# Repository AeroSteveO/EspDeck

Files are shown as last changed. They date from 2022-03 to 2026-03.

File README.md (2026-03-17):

# EspDeck

This is a StreamDeck inspired macro pad powered by EspHome for use with Home Assistant. Each key has 3 different actions it can perform, single click, double click, and click + hold. These can all be tied to different automations in Home Assistant. This project is made for ESPHome (hardware + ESPHome Configuration).

Made for ESPHome (https://esphome.io/guides/made_for_esphome.html)

# Functionality
ESPDeck provides a macropad type input set to Home Assistant based on ESPHome. This includes 3 modes of input for each keyswitch. 

  * Single Click
  * Double Click
  * Click and Hold

# Variants
There are a number of variants of the device in this repository. The standard EspDeck is a 9 key pad. There is also the novelkey macropad, which has two BIG switches, and an upcoming design to add NFC functionality to the EspDeck macropad (NfcDeck). All of these use the same basic features in ESPHome and previous iterations of the designs are maintained for legacy support. Do look at the variant specific README files for the hardware needed, 3d print files, and yaml configurations.

## EspDeck
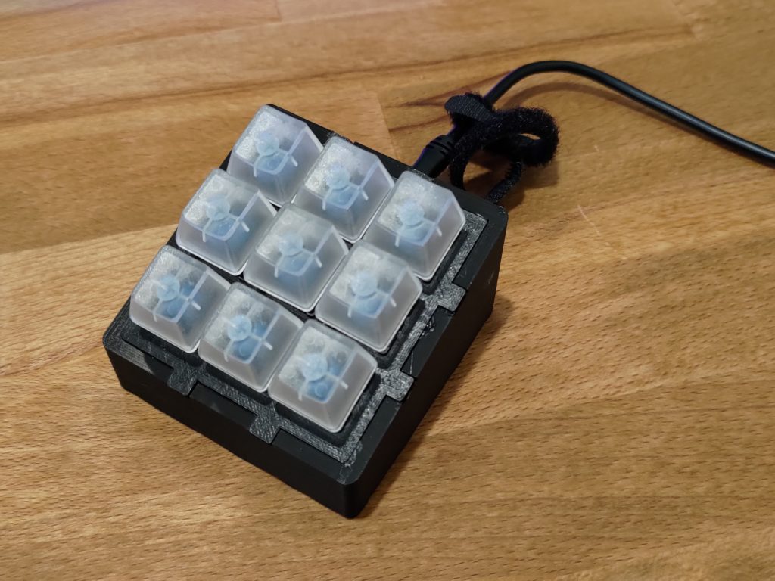
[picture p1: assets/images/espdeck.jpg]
EspDeck


There are also previous generation EspDecks ([Gen 1](/espdeck/GEN1_README.md), [Gen 2](/espdeck/GEN2_README.md)) in this repository.

## NfcDeck
NfcDeck

### Additional Functionality

  * NFC Card Reader
  * Rotary Encoder
  * Per Key Addressable Backlighting

## Novelkey Novelty macropad
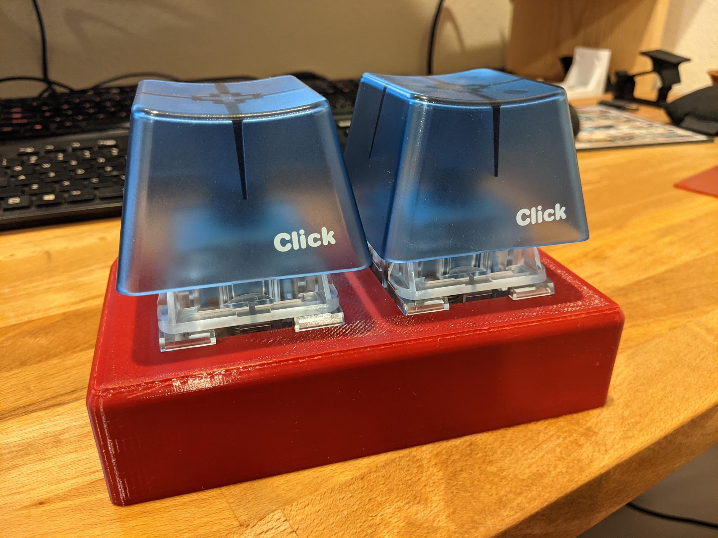
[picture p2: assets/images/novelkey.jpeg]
Novelkey Novelty Big Switch Macropad


### Additional Functionality

  * Per Key LED Backlighting
  * BIG switches

# Hardware Used
  * 1 x ESP8266 / NodeMCU
  * 9 x Relegendable KeyCaps (waterslide decal paper can also be used with existing keycaps, especially blank ones)
  * 9 x Mechanical key switches
  * Hot Glue
  * 3d printer material
  * various wire

# STL Files for 3D Printing
All the case designs can be found on Github, [Printables](https://www.printables.com/@AeroSteveO/collections/1135401), and [Thingiverse](https://www.thingiverse.com/aerosteveo/collections/40893020/things)

# Configuration
EspHome YAML files are included with each project and are versioned to allow for legacy device support.

# Printing Instructions
These can be printed with low infill for speed and with a medium to thick layer height, they don't need a fine layer height to print well. All the designs are intended to be printed without supports (except the main enclosure for the novelkey novelty macropad). 

# Contributing
Contributions are welcome to the project

# Change Log

  * With generation 2, we simplified the design, reducing the number of resistors needed in the wiring.
  * With generation 3, we begin to use the Matrix Keypad feature of EspHome, simplifying the wiring.

# To Do:
  * Update the case designs to use heat set inserts to make them more maintainable rather than hot gluing the top down, also more professional
  * Add WS2812 LEDs to backlight the key switches, providing an aveneue for notifying of a status from home assistant on the OG ESP Deck Designs
  * Create a 3 key NFC deck variant with 2 key switches and a rotary (or keyswitch for the third)

# Star History
(you guys rock)
Star History Chart (https://www.star-history.com/#AeroSteveO/EspDeck&type=date&legend=top-left)

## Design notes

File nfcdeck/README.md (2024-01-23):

# NFC Deck
This is a complex iteration of the EspDeck in order to allow control of multi room audio systems (or anything else you want to use it for). There are two top panel iterations, one for 9 mechanical key switches, and one for 8 key switches and one rotary encoder.

# Variants:
  * 8 Keys, 1 Rotary Knob
  * 9 Keys
  * 2 Keys, 1 Rotary Knob
  * 3 Keys

# Components:
Since this has a few different variants you can build. We split the parts list up into the common parts for all models, and then the parts specific to each model. This are mostly different based on the counts for different parts.

## Common to All
  * ESP32 DevKitv1
  * 1 x NFC Card Reader
  * 1 x Piezo Buzzer
  * 4 x [Rubber Feet](https://www.amazon.com/dp/B06XPCLN23)
  * 4 x M2 heat set inserts
  * 4 x M2 screws

## 9 Key + Rotary
  * 8  x Mechanical Key Switches
  * 8  x Relegendable Key Caps
  * 1  x Rotary Encoder
  * 1  x Knob
  * 8  x WS2812 LEDs (60 LED per M, or 16.5mm interval)
  * 2  x 100 ohm resistors
  * 2  x 1 uf capcitors

## 9 Key
  * 9  x Mechanical Key Switches
  * 9  x Relegendable Key Caps
  * 9  x WS2812 LEDs (60 LED per M, or 16.5mm interval)

## 3 Key + Rotary
  * 2  x Mechanical Key Switches
  * 2  x Relegendable Key Caps
  * 1  x Rotary Encoder
  * 1  x Knob
  * 2  x WS2812 LEDs (60 LED per M, or 16.5mm interval)
  * 2  x 100 ohm resistors
  * 2  x 1 uf capcitors

## 3 Key
  * 3  x Mechanical Key Switches
  * 3  x Relegendable Key Caps
  * 3  x WS2812 LEDs (60 LED per M, or 16.5mm interval)

# Circuit Diagram
NFC Deck Circuit Diagram

## Breaking the circuits down into individual components
9 Key Circuit Diagram
Buzzer Circuit Diagram
LED Strip Circuit Diagram
NFC Circuit Diagram

Rotary Encoder Circuit Diagram

# Wiring
- Assemble a small circuit board with the rotary encoder 

# Assembly

- Print out the top plate, and mount all of your key switches to it and the rotary encoder.
- Solder all the key switches and rotary up to the D1 Mini

Also, make sure that you have set the switches on the PN532 to the following:
- Switch 1: On (up)
- Switch 2: Off (down)

This enables the PN532 module to communicate with the D1 over I2C, and is required for the modules to work together!

- Optionally electrical tape over the NFC module power LED

Mount the NFC module to the top plate

# Printing Instructions
Print one each of:

 *  nfcdeck_base.stl
 *  NfcDeck Top Piece (one of either option)
	*  nfcdeck_top_rotary.stl (with a space for a rotary encoder)
	*  nfcdeck_top_9key.stl   (with 9 key switches and no rotary encoder)

These can be low infill as they don't require much structural stability
Do use a slightly larger layer thickness for the top piece, 0.15mm is good, or more. The details come out a bit better in the home assistant logo using that higher layer thickness.

Work is still continuing on the 3 key designs, so they aren't yet available.

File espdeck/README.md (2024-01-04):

# EspDeck

This is a StreamDeck inspired macro pad powered by EspHome for use with Home Assistant. Each key has 3 different actions it can perform, single click, double click, and click + hold. These can all be tied to different automations in Home Assistant. This project is made for ESPHome (hardware + ESPHome Configuration).

Made for ESPHome (https://esphome.io/guides/made_for_esphome.html)

# Functionality
ESPDeck provides a macropad type input set to Home Assistant based on ESPHome. This includes 3 modes of input for each keyswitch. 

  * Single Click
  * Double Click
  * Click and Hold

See also the previous generation EspDecks ([Gen 1](GEN1_README.md), [Gen 2](GEN2_README.md)) in this repository.

# Hardware Used
  * 1 x ESP8266 / NodeMCU
  * 9 x Relegendable KeyCaps (waterslide decal paper can also be used with existing keycaps, especially blank ones)
  * 9 x Mechanical key switches
  * Hot Glue
  * 3d printer material
  * various wire

# Case

Case design based off of: https://www.thingiverse.com/thing:5204033. I extended the height of the case for my inefficient use of space inside of it, I also made some modifications to better hold the Esp8266. The top of the case is currently press fit or hot glued on, though I'll be working on making it a screw in place top in the future.

Case design can also be found here: https://www.thingiverse.com/thing:5223223

# Wiring
The wiring is simple enough, we make use of the matrix keypad feature and wire the columns and rows to inputs on the ESP. We avoid GPIO15 as it doesn't have an internal pullup as well, simplifying our wiring.

Third Generation Circuit Diagram

# Configuration

keypad3.yaml

# Printing Instructions
Print one each of:
  * MacroPadBottomExtended.stl
  * MacroPadTop.stl

These can be printed with low infill for speed.

# Contributing
Contributions are welcome to the project

# Change Log

  * With generation 3, we begin to use the Matrix Keypad feature of EspHome, simplifying the wiring.
  * With generation 4, we'll be adding WS2812 LEDs to backlight the key switches, providing an aveneue for notifying of a status from home assistant

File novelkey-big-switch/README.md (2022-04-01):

# Novelkey "The Big Switch" ESP Home MacroPad
This is a simple 2 switch ESP Home based macropad for use with home assistant. I built these for nightstand switches for the lights and overhead fan in the room (or as an excuse to play with the novelkeys big switches). They have RGB backlighting to provide feedback of what functionality is on what key (or whatever else you want to use the lighting for).

# Components:
  * ESP8266 / NodeMCU
  * 2 x [NovelKey "The Big Switch" mechanical keyboard switches](https://novelkeys.com/products/the-big-switch-series)
  * 2 x [Common Cathode RGB LEDs](https://www.amazon.com/dp/B0749MD16P)
  * 2 x [300 ohm resistors](https://www.amazon.com/dp/B07HDH7QK5)
  * 3 x [pairs of 3-pin JST plugs](https://www.amazon.com/gp/product/B071H5XCN5) (I got them originally for WLED strips)
  * 4 x [Rubber Feet](https://www.amazon.com/dp/B06XPCLN23)

# Circuit Diagram
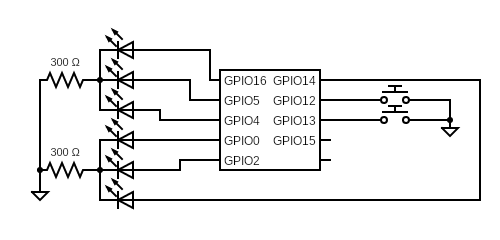
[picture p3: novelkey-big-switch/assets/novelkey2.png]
First Generation Circuit Diagram


# Printing Instructions
Print one each of:

 *  big_base.stl
 *  big_bottom.stl
 *  big_cover.stl

These can be low infill as they don't require much structural stability

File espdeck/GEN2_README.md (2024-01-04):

# EspDeck

This is a StreamDeck inspired macro pad powered by EspHome for use with Home Assistant. Each key has 3 different actions it can perform, single click, double click, and click + hold. These can all be tied to different automations in Home Assistant. This project is made for ESPHome (hardware + ESPHome Configuration).

Made for ESPHome (https://esphome.io/guides/made_for_esphome.html)

# Functionality
ESPDeck provides a macropad type input set to Home Assistant based on ESPHome. This includes 3 modes of input for each keyswitch. 

  * Single Click
  * Double Click
  * Click and Hold

See also the Novelkey Novelty Big Switch Macropad and the [Gen 1 EspDeck](GEN1_README.md) is also documented.

# Hardware Used
  * 1 x ESP8266 / NodeMCU
  * 9 x Relegendable KeyCaps (waterslide decal paper can also be used with existing keycaps, especially blank ones)
  * 9 x Mechanical key switches
  * 1 x 10k Resistor
  * Hot Glue
  * 3d printer material
  * various wire

# Case

Case design based off of: https://www.thingiverse.com/thing:5204033. I extended the height of the case for my inefficient use of space inside of it, I also made some modifications to better hold the Esp8266. The top of the case is currently press fit or hot glued on, though I'll be working on making it a screw in place top in the future.

Case design can also be found here: https://www.thingiverse.com/thing:5223223

# Wiring
The wiring is simple enough, one end of the switch going to the digitial IO pin, and the other end to ground, and set up ESPHome to have the internal pullup enabled on the ESP8266 device. Two of the GPIOs on the device cannot be done this way, GPIO16 needs an external pullup resistor, and GPIO15 needs to be inverted (internal pulldown, external pullup).

Second Generation Circuit Diagram

Second Generation Circuit Diagram Simplified

# Configuration

keypad2.yaml

# Printing Instructions
Print one each of:
  * MacroPadBottomExtended.stl
  * MacroPadTop.stl

These can be printed with low infill for speed.

# Contributing
Contributions are welcome to the project

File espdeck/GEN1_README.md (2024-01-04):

# Functionality
ESPDeck provides a macropad type input set to Home Assistant based on ESPHome. This includes 3 modes of input for each keyswitch. 

  * Single Click
  * Double Click
  * Click and Hold

# Hardware Used
  * 1 x ESP8266 / NodeMCU
  * 9 xRelegendable KeyCaps (waterslide decal paper can also be used with existing keycaps, especially blank ones)
  * 9 x Mechanical key switches
  * Hot Glue
  * 3d printer material
  * 9 x 10k Ohm Resistors

# Wiring
## Gen1 Design
3.3V to the switches

10k to ground for each Digitial IO Pin, as well as a line to the switch

First Generation Circuit Diagram

# Configuration
keypad.yaml

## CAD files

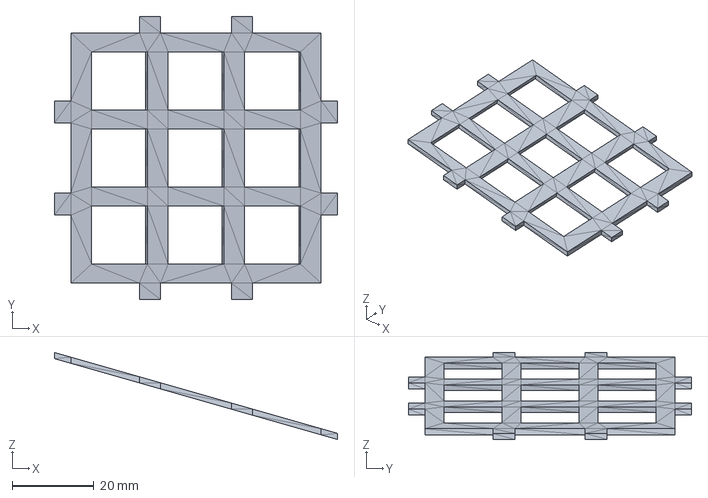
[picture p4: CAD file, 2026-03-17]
espdeck/MacroPadTop.stp
69.4 x 69.4 x 21.3 mm

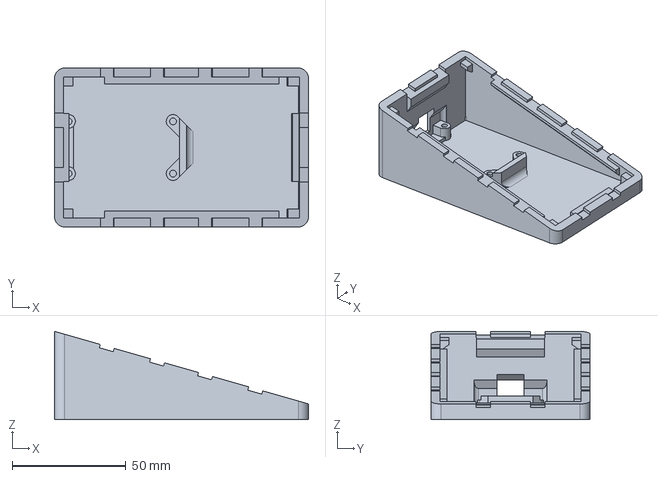
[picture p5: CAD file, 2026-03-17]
nfcdeck/case_models/nfcdeck_base.stp
111.8 x 70.0 x 38.9 mm

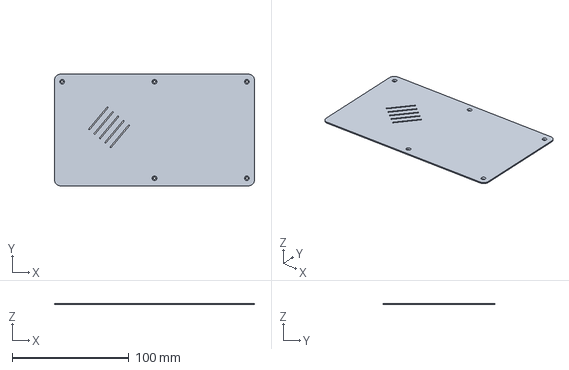
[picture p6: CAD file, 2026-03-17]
novelkey-big-switch/big_bottom.stp
171.6 x 95.8 x 1.00 mm

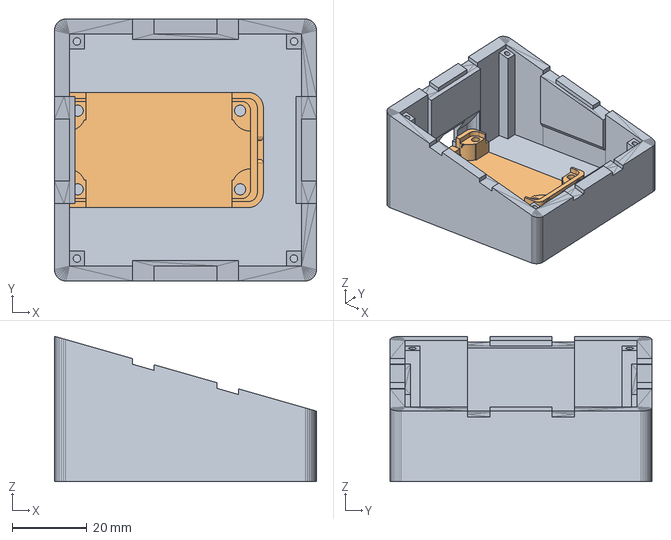
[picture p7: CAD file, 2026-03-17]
espdeck/MacroPadBotom.stp
70.0 x 70.0 x 38.8 mm

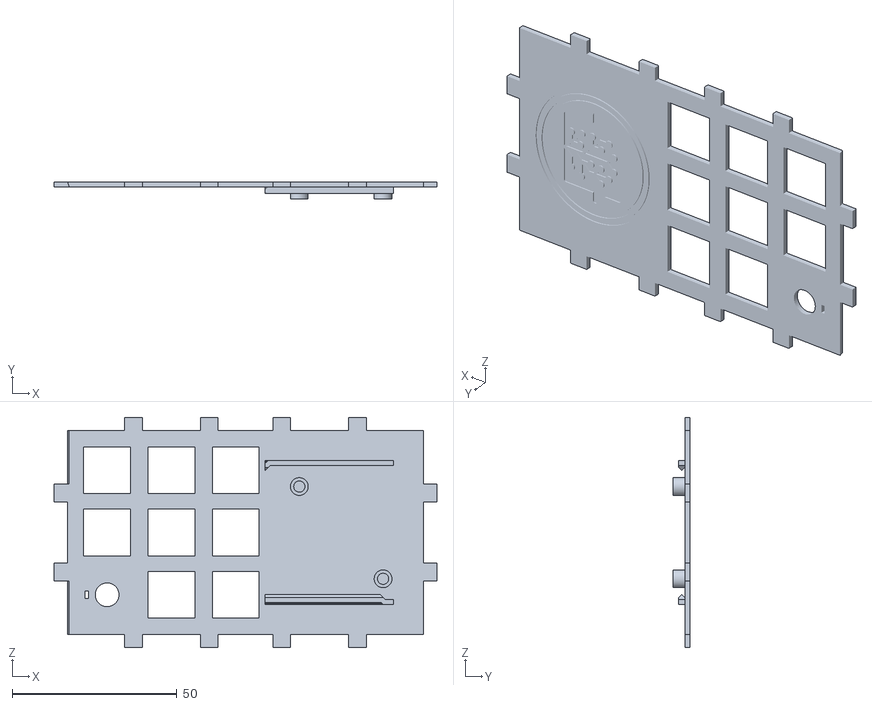
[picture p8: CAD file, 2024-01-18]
nfcdeck/case_models/nfcdeck_top_rotary.stl
116.2 x 5.10 x 69.9

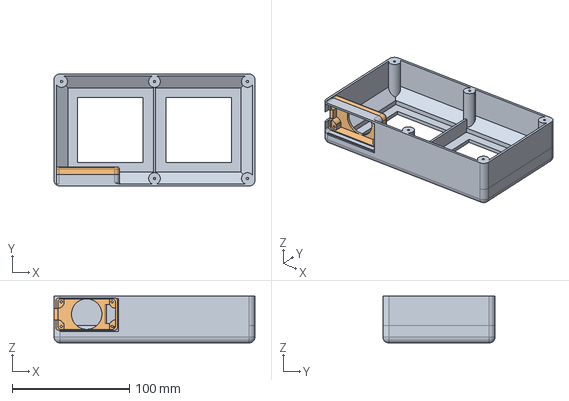
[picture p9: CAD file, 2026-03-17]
novelkey-big-switch/big_base.stp
171.6 x 95.8 x 40.0 mm

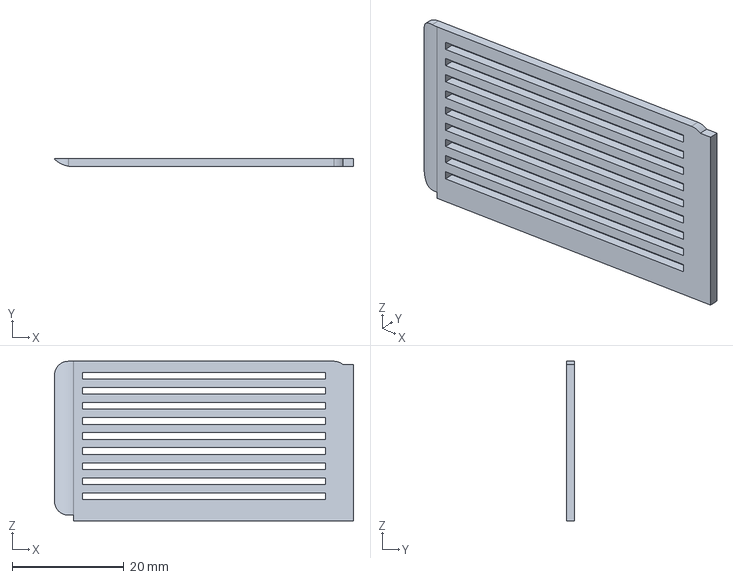
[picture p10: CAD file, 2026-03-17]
novelkey-big-switch/big_cover.stp
53.6 x 1.50 x 28.6 mm

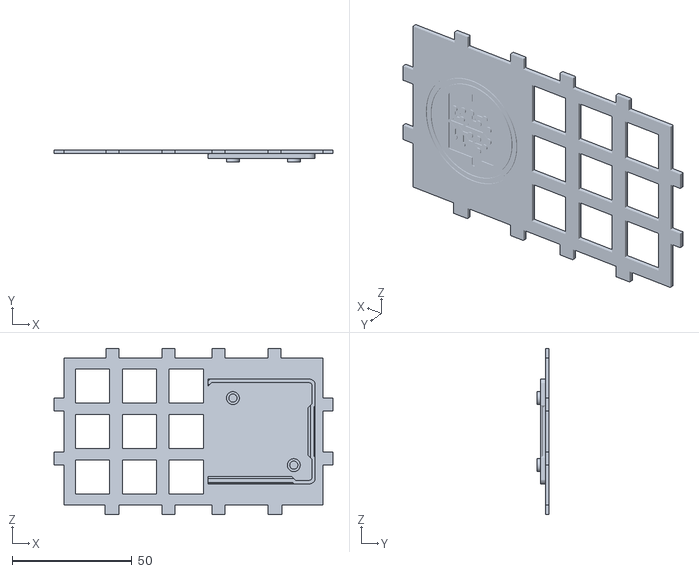
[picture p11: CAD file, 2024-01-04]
nfcdeck/case_models/nfcdeck_top.stl
116.5 x 5.10 x 69.4

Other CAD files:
espdeck/MacroPadBottomExtended.stl
nfcdeck/case_models/nfcdeck_top_9key.stl
espdeck/MacroPadTop.stl
nfcdeck/case_models/nfcdeck_base.stl
novelkey-big-switch/big_base.stl
novelkey-big-switch/big_bottom.stl
novelkey-big-switch/big_cover.stl

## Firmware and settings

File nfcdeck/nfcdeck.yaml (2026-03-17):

esphome:
  name: esphome-web-asdf
  friendly_name: NfcDeck
  project:
    name: aerosteveo.nfc_deck
    version: "1.0"
  # If buzzer is enabled, notify on api connection success
  on_boot:
    priority: -10
    then:
    - lambda: !lambda |-
            id(key_1_click_state).publish_state(false);
            id(key_2_click_state).publish_state(false);
            id(key_3_click_state).publish_state(false);
            id(key_4_click_state).publish_state(false);
            id(key_5_click_state).publish_state(false);
            id(key_6_click_state).publish_state(false);
            id(key_7_click_state).publish_state(false);
            id(key_8_click_state).publish_state(false);
            id(key_9_click_state).publish_state(false);
            id(key_1_held_state).publish_state(false);
            id(key_2_held_state).publish_state(false);
            id(key_3_held_state).publish_state(false);
            id(key_4_held_state).publish_state(false);
            id(key_5_held_state).publish_state(false);
            id(key_6_held_state).publish_state(false);
            id(key_7_held_state).publish_state(false);
            id(key_8_held_state).publish_state(false);
            id(key_9_held_state).publish_state(false);
            id(key_1_double_click_state).publish_state(false);
            id(key_2_double_click_state).publish_state(false);
            id(key_3_double_click_state).publish_state(false);
            id(key_4_double_click_state).publish_state(false);
            id(key_5_double_click_state).publish_state(false);
            id(key_6_double_click_state).publish_state(false);
            id(key_7_double_click_state).publish_state(false);
            id(key_8_double_click_state).publish_state(false);
            id(key_9_double_click_state).publish_state(false);
    - wait_until:
        api.connected:
    - logger.log: API is connected!
    - rtttl.play: "success:d=24,o=5,b=100:c,g,b"
    - light.turn_on:
        id: activity_led
        brightness: 100%
        red: 0%
        green: 0%
        blue: 100%
        flash_length: 500ms
    - switch.turn_on: buzzer_enabled
    - switch.turn_on: led_enabled

substitutions:
  name: esphome-web-asdf
  friendly_name: NfcDeck
  nine_key_pin_1: "13"
  nine_key_pin_2: "12"
  nine_key_pin_3: "14"
  nine_key_pin_4: "27"
  nine_key_pin_5: "26"
  nine_key_pin_6: "25"
  i2c_sda_pin: "23"
  i2c_scl_pin: "22"
  buzzer_output_pin: "1"
  rotary_pin_a: "3"
  rotary_pin_b: "21"
  neopixelbus_pin: "19"

esp32:
  board: esp32dev
  framework:
    type: esp-idf

# This should point to the public location of this yaml file.
dashboard_import:
  package_import_url: github://AeroSteveO/EspDeck/nfcdeck/nfcdeck.yaml

# Enable logging
logger:

# Enable Home Assistant API
api:
  encryption:
    key: "asdfasdfasdfasdfasdfasdf"
  services:
  - service: rfidreader_tag_ok
    then:
    - rtttl.play: "beep:d=16,o=5,b=100:b"
  - service: rfidreader_tag_ko
    then:
    - rtttl.play: "beep:d=8,o=5,b=100:b"

  - service: play_rtttl
    variables:
      song_str: string
    then:
    - rtttl.play: !lambda 'return song_str;'

  - service: write_tag_id
    variables:
      tag_id: string
    then:
    - light.turn_on:
        id: activity_led
        brightness: 100%
        red: 100%
        green: 0%
        blue: 0%    
    - lambda: |-
        auto message = new nfc::NdefMessage();
        std::string uri = "https://www.home-assistant.io/tag/";
        uri += tag_id;
        message->add_uri_record(uri);
        id(pn532_board).write_mode(message);
    - rtttl.play: "write:d=24,o=5,b=100:b"
    - wait_until:
        not:
          pn532.is_writing:
    - light.turn_off:
        id: activity_led
    - rtttl.play: "write:d=24,o=5,b=100:b,b"

  - service: write_music_tag
    variables:
      music_url: string
      music_info: string
    then:
    - light.turn_on:
        id: activity_led
        brightness: 100%
        red: 100%
        green: 0%
        blue: 0%    
    - lambda: |-
        auto message = new nfc::NdefMessage();
        std::string uri = "";
        std::string text = "";
        uri += music_url;
        text += music_info;
        if ( music_url != "" ) {
          message->add_uri_record(uri);
        }
        if ( music_info != "" ) {
          message->add_text_record(text);
        }
        id(pn532_board).write_mode(message);
    - rtttl.play: "write:d=24,o=5,b=100:b"
    - wait_until:
        not:
          pn532.is_writing:
    - light.turn_off:
        id: activity_led
    - rtttl.play: "write:d=24,o=5,b=100:b,b"

ota:
  platform: esphome

wifi:
  ssid: !secret wifi_ssid
  password: !secret wifi_password

  # Enable fallback hotspot (captive portal) in case wifi connection fails
  ap:
    ssid: "Esphome-Web-asdf"
    password: "asdfasdfasdfasdfasdf"

captive_portal:
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

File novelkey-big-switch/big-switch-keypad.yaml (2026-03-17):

esphome:
  name: novelkey2
  project:
    name: "NovelKey.v1"
    version: "1.0.0"

esp8266:
  board: esp12e

# Enable logging
logger:

# Enable Home Assistant API
api:
  password: ""

ota:
  platform: esphome
  password: ""

dashboard_import:
  package_import_url: github://AeroSteveO/EspDeck/novelkey-big-switch/big-switch-keypad.yaml

wifi:
  ssid: !secret wifi_ssid
  password: !secret wifi_password

  # Enable fallback hotspot (captive portal) in case wifi connection fails
  ap:
    ssid: "Novelkey2 Fallback Hotspot"
    password: "bigLongUniqueString"

captive_portal:


switch:
  - platform: gpio
    pin: 16
    id: red
    name: "Novelkey 1 Red"
    restore_mode: RESTORE_DEFAULT_OFF
    interlock: [blue,green]
  - platform: gpio
    pin: 5
    id: green
    name: "Novelkey 1 Green"
    restore_mode: RESTORE_DEFAULT_OFF
    interlock: [blue,red]
  - platform: gpio
    pin: 4
    id: blue
    name: "Novelkey 1 Blue"
    restore_mode: RESTORE_DEFAULT_OFF
    interlock: [red,green]
  - platform: gpio
    pin: 0
    id: red2
    name: "Novelkey 2 Red"
    restore_mode: RESTORE_DEFAULT_OFF
    interlock: [blue2,green2]
  - platform: gpio
    pin: 2
    id: green2
    name: "Novelkey 2 Green"
    restore_mode: RESTORE_DEFAULT_OFF
    interlock: [blue2,red2]
  - platform: gpio
    pin: 14
    id: blue2
    name: "Novelkey 2 Blue"
    restore_mode: RESTORE_DEFAULT_OFF
    interlock: [red2,green2]
binary_sensor:
  - platform: gpio
    pin:
      number: 12
      mode:
        input: true
        pullup: true
      inverted: true
    name: "Novelkey Switch 1"


  - platform: gpio
    pin:
      number: 13
      mode:
        input: true
        pullup: true
      inverted: true
    name: "Novelkey Switch 2"
    
- platform: status
    name: "Keypad Status"

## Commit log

2022-01-29 Add files via upload
    Macro Pad Case based off of https://www.thingiverse.com/thing:5204033 from andrew_takeshi on thingiverse
    [MacroPadBottomExtended.stl, MacroPadTop.stl]
2022-02-01 adding the circuit diagrams
2022-02-02 updating circuit to the final design
2022-02-02 updating to the final design where GPIO16 doesn't support an input pullup (thus requiring an external pullup, and GPIO15 needs to be low at boot, so also does not support an input pullup.
    [keypad2.yaml]
2022-03-29 adding new config for the big switch keypad
2022-03-29 adding the designs for the macropad case
    adding the designs for the macropad case
    [big_base.stl, big_bottom.stl, big_cover.stl]
2022-03-29 adding link to the big switch variant
2022-04-01 clarifying wiring instructions
2022-07-27 adding an initial state to all the buttons and template buttons
2023-01-22 Update big-switch-keypad.yaml
    fixing the link i think
    [big-switch-keypad.yaml]
2023-02-25 moving gen2 to its own separate file spot off of the main readme. Updated the main readmes to gen 3
    [MacroPadBottomExtended.stl]
2024-01-04 massive repo reorganization to make it easier to maintain the various types of macro pads in the EspDeck lineup, also some initial commits for the NFC Deck
    [MacroPadBottomExtended.stl, MacroPadTop.stl, nfcdeck_base.stl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]
2024-01-18 lets get this into a decent alpha state
    [nfcdeck_base.stl, nfcdeck_top_9key.stl, nfcdeck_top_rotary.stl]
2024-01-23 circuit diagram updates
2024-09-18 Update nfcdeck.yaml
    giving max/min values for the rotary encoder
2024-11-09 Update nfcdeck.yaml
    using esp-idf platform and a different light platform to avoid issues with ota updates that the esp32's i use have been having
    [nfcdeck.yaml]
2025-02-23 fixing compatibility with latest esphome
    [nfcdeck.yaml]
2026-03-17 adding step files for everything
    [MacroPadBotom.stp, MacroPadTop.stp, big_base.stp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]
